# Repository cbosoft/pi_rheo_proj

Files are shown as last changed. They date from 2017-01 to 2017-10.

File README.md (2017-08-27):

# RPi-R #

Raspberry Pi Rheometer. A rheometer using a Taylor-Couette cell along with 
a plethora of sensors to record a bunch of data like temperature, revolution
speed, motor supply current etc etc.

The project has been extended, so more effort can be put into designing the 
hardware.

With now a choice of motor and what-have-you, a better (read: working) rheometer
can be produced in the next few months. A few different design are being considered,
one possible novel method which could be cool (although there is nothing new under
the sun, someone must have tried it before).

I have started with a software overhaul, and will continue to ponder what direction
to go in with the hardware until October, when I will begin to put plans into action.

## Changelog ##

**v0.1.5**

- Cleaned up gui
- Rewrote recalibration algo
- Added cal override (if cal is wrong or previous was better whatever)
- General tidying of script
- Removed quick run as an option (when would this ever be used?)
- Added info about why each package is being imported
- Removed "Plot" as a main menu option - this may return later on
- Removed complex menu system
- Removed rheometry calculation function (was incorrect anyway)

## Rough Index ##

```
/bin                            code lives here
/etc/data.xml                   meta data lives here (calibrations, rheometer geometry)
/logs                           data logged from experimental runs lives here (temporary)
/misc/datasheets                hardware datasheets live here
/plot                           scripts for plotting results live here
```

## License Spiel ##

*Distributed under GNU General Public License (GPL).*

*You can use this as much as you like, share it as you like, whatever.*

*However, there is no warranty or guarantee that it will actually work.*

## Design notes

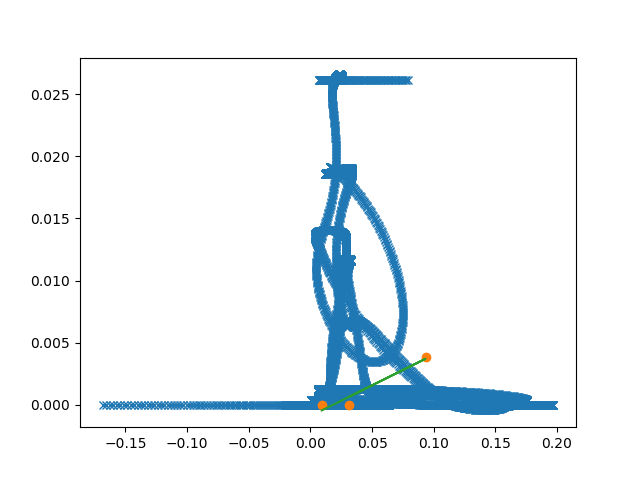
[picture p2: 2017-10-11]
etc/trd.png

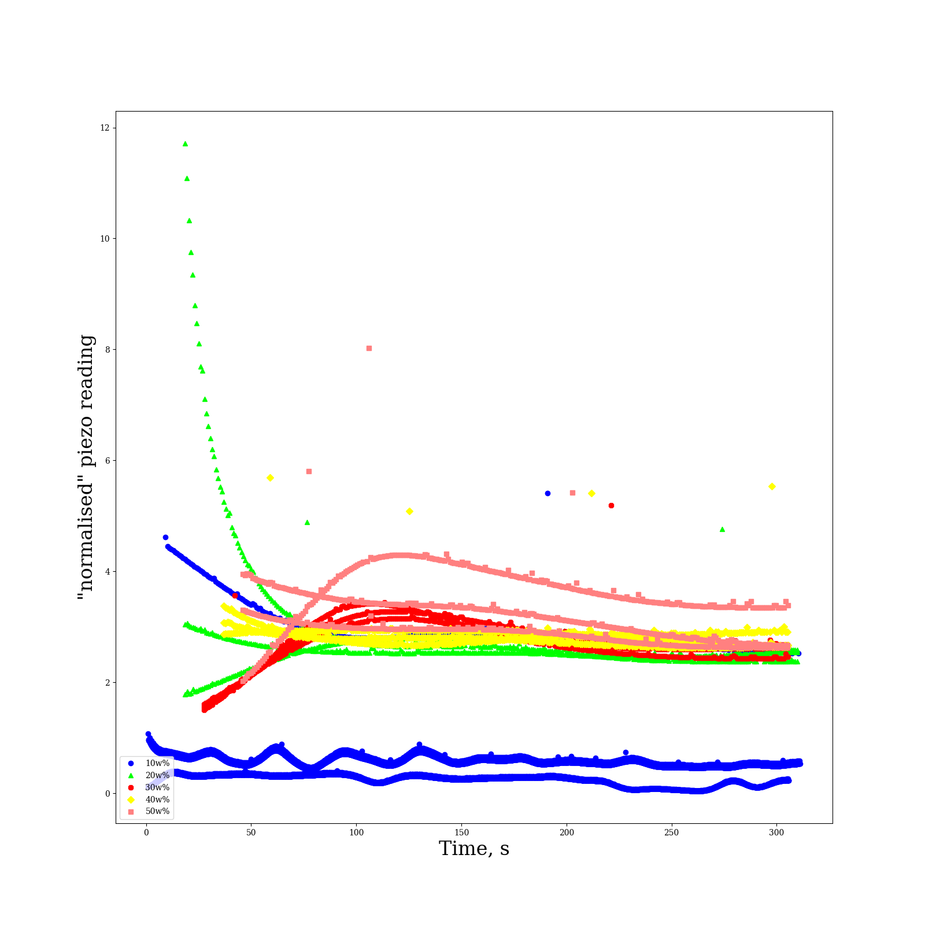
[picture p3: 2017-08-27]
plots/logs_piezo_compare_normalised.png

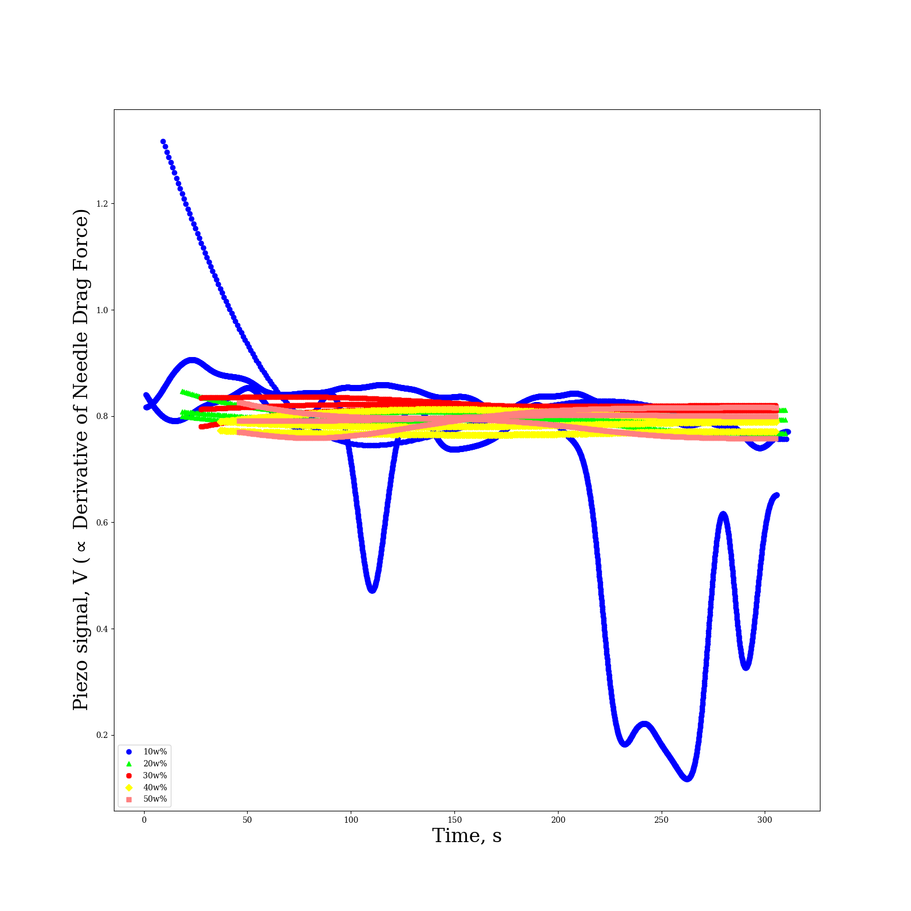
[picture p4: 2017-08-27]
plots/logs_piezo_compare.png

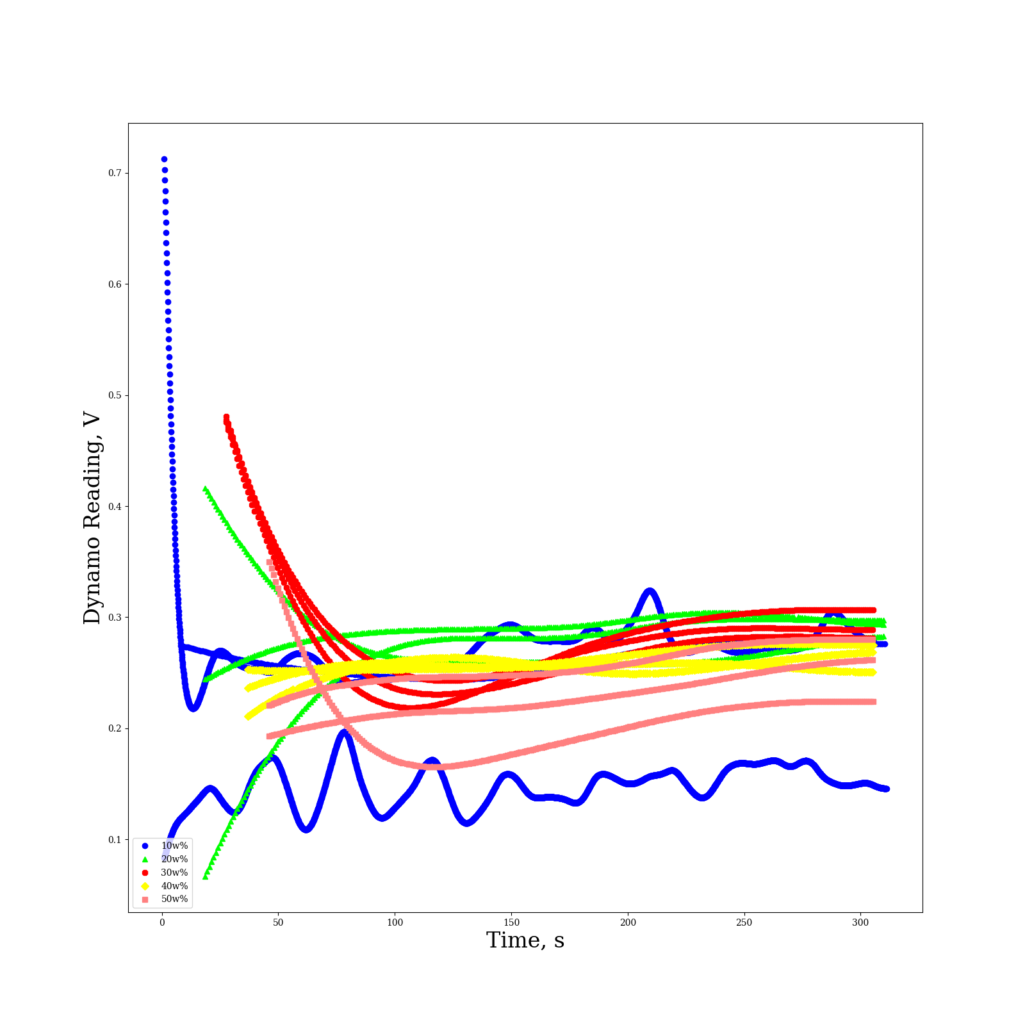
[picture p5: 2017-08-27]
plots/logs_piezo_compare_speeds.png

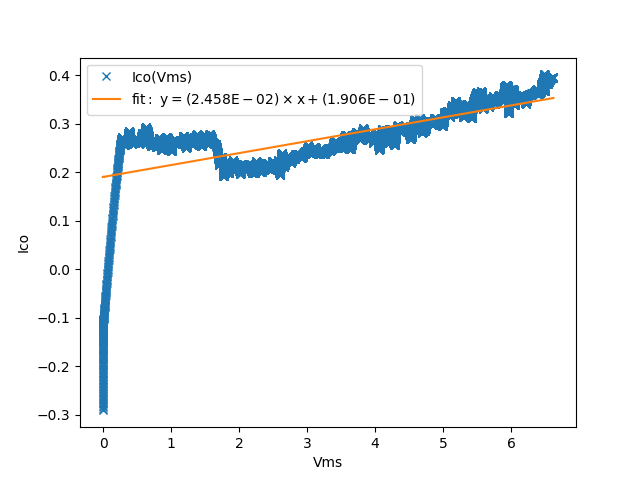
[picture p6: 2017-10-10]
plots/cal_cur.png

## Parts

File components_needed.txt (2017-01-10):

Component,Size,Link
Motor Speed Controller,,
Digital Potentiometer,10k,http://uk.rs-online.com/web/p/digital-potentiometers/6878458/
Digital Pot Surface Mount to Through Hole,MSOP,http://uk.rs-online.com/web/p/surface-mount-smt-to-through-hole-adapter-boards/6564897/
Capacitor 1,10uF,http://uk.rs-online.com/web/p/aluminium-capacitors/0117035/
Capacitor 2,470uF,http://uk.rs-online.com/web/p/aluminium-capacitors/5261884/
Transistor,max 65w and 6A,http://uk.rs-online.com/web/p/bipolar-transistors/7905292/

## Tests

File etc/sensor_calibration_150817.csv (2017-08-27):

t | dr | cr | cr2a | cr2b | pv | fdr | fcr | T | Vpz1 | Vpz2 | Vpzbg | Vadcbg
1502799552.038952 | 0.200 | 0.754 | 1.470 | 1.473 | 0 | 0.200 | 0.754 | 0.000 | 0.0580078125 | 0.01611328125 | 0.01611328125 | 0.02578125
1502799552.141647 | 0.738 | 0.754 | 1.476 | 1.470 | 0 | 0.738 | 0.754 | 0.000 | 0.0580078125 | 0.0 | 0.0 | 0.0
1502799552.243836 | 0.645 | 0.754 | 1.473 | 1.473 | 0 | 0.645 | 0.754 | 0.000 | 0.0580078125 | 0.0 | 0.0 | 0.0
1502799552.347707 | 0.677 | 0.754 | 1.502 | 1.492 | 0 | 0.677 | 0.754 | 0.000 | 0.0580078125 | 0.0064453125 | 0.0064453125 | 0.0064453125
1502799552.450571 | 0.625 | 0.780 | 1.511 | 1.502 | 0 | 0.625 | 0.780 | 0.000 | 0.064453125 | 0.0064453125 | 0.0064453125 | 0.0064453125
1502799552.552842 | 0.110 | 0.777 | 1.508 | 1.492 | 0 | 0.110 | 0.777 | 0.000 | 0.05478515625 | 0.00322265625 | 0.00322265625 | 0.0
1502799552.654741 | 0.148 | 0.780 | 1.508 | 1.502 | 0 | 0.148 | 0.780 | 0.000 | 0.05478515625 | 0.00322265625 | 0.00322265625 | 0.00322265625
1502799552.756504 | 0.145 | 0.780 | 1.518 | 1.492 | 0 | 0.145 | 0.780 | 0.000 | 0.05478515625 | 0.0 | 0.0 | 0.0
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

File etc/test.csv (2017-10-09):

t | f_spd0 | r_spd0 | f_spd1 | r_spd1 | f_spd2 | r_spd2 | cra | crb | pv | T | Vpz | Vms
1507542908.593720 | 0.000 | 0.000 | 0.000 | 0.000 | 0.000 | 0.000 | 2.519 | 0.039 | 25.000 | 0.000 | 0.0870967741935 | 0.000
1507542908.605269 | 0.000 | 0.000 | 0.000 | 0.000 | 0.000 | 0.000 | 2.490 | 0.003 | 25.000 | 0.000 | 0.0451612903226 | 0.000
1507542908.616724 | 0.000 | 0.000 | 0.000 | 0.000 | 0.000 | 0.000 | 2.500 | 0.000 | 25.000 | 0.000 | 0.0 | 0.000
1507542908.628102 | 0.000 | 0.000 | 0.000 | 0.000 | 0.000 | 0.000 | 2.494 | 0.035 | 25.000 | 0.000 | 0.103225806452 | 0.013
1507542908.639447 | 0.000 | 0.000 | 0.000 | 0.000 | 0.000 | 0.000 | 2.526 | 0.000 | 25.000 | 0.000 | 0.0 | 0.052
1507542908.650724 | 0.000 | 0.000 | 0.000 | 0.000 | 0.000 | 0.000 | 2.513 | 0.055 | 25.000 | 0.000 | 0.135483870968 | 0.052
1507542908.662021 | 0.000 | 0.000 | 0.000 | 0.000 | 0.000 | 0.000 | 2.555 | 0.000 | 25.000 | 0.000 | 0.0 | 0.065
1507542908.673295 | 0.000 | 0.000 | 0.000 | 0.000 | 0.000 | 0.000 | 2.516 | 0.035 | 25.000 | 0.000 | 0.0838709677419 | 0.077
1507542908.684552 | 0.000 | 0.000 | 0.000 | 0.000 | 0.000 | 0.000 | 2.542 | 0.000 | 25.000 | 0.000 | 0.0322580645161 | 0.116
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

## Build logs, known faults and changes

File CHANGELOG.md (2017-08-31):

## v0.1.8 ##
- Control script overhaul

## v0.1.7 ##
- Tidied display function
- Removed 30AHES recording
- Added dynamo filter recording and speed calculation

## v0.1.6 ##
- Added proper changelog tracking
- Added rheology data calculation to logger
- Added motor calibration
- Tidied plothelp.py
- Added general plot function to plothelp.py
- Started docstring overhaul

## v0.1.5 ##

- Cleaned up gui
- Rewrote recalibration algo
- Added cal override (if cal is wrong or previous was better or whatever)
- General tidying of script
- Removed quick run as an option (when would this ever be used?)
- Added info about why each package is being imported
- Removed "Plot" as a main menu option - this may return later on
- Removed complex menu system
- Removed rheometry calculation function (was incorrect anyway)

## v0.1.3 and previous ##

- All knowledge of this period has been lost in the annals of history
- It can be inferred that at some point The Software was written, and at some point The Hardware was assembled.

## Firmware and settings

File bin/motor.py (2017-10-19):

'''
    Facilitates the control of a motor using dig_pot.py and adc.py.
    
    Controls the supply voltage sent to the motor in to control the speed.
    Data is logged using methods from adc.py. Noise is removed from the data
    using methods from filter.py. Temperature sensing data is obtained using
    tempsens.py.
    
    Author: Chris Boyle (christopher.boyle.101@strath.ac.uk)
'''

# System
import sys
import time
import os
import thread as td
from warnings import warn

# 3rd Party
try:
    import RPi.GPIO as gpio
except ImportError:
    import dummygpio as gpio
import numpy as np
#from PID import PID as pid

# RPi-R
#from filter import filter as ft
#from dig_pot import MCP4131 as dp
from adc import MCP3008 as ac
from control import pid_controller as pid
from tempsens import ds18b20 as ts
import dproc

class motor(object):
    '''
    Usage:
    
    object = motor.motor(**kwargs)
    
    Creates a new instance of a motor interface object.
    
    **kwargs:
        startnow        (bool)          Start polling as soon as the instance is created
        adc_vref        (float)         Voltage reference value. Default is 3.3
        poll_logging    (bool)          Indicates whether to log to file or not. Default is True.
        therm_sn        (string)        Serial number of the thermocouple. Used in 1-wire communication.
                                        Default is '28-0316875e09ff'
        i_poll_rate     (float)         Inverse poll rate: time to wait in between logging data. Default is 0.1
        pic_tuning      (float, float)  Tuning of PI controller. Kp and Ki respectively. Default is (0.2, 0.15)
        relay_pin       (integer)       Pin number which can be used to control the relay.
    '''
    # Logging
    poll_running = False  # is the speed currently being polled?
    poll_logging = True  # Will log every (i_poll_rate)s if this is True
    this_log_name = ""
    debug = False

    def __init__(self, startnow=False, adc_vref=3.3, poll_logging=True, therm_sn="28-0316875e09ff",
                 log_interval=0.01, tuning=(1.8, 2.845, 0.0), opt_pins=[21]):
        '''
        object = motor.motor(**kwargs)
        
        Creates a new instance of a motor interface object.
        
        **kwargs:
            startnow        (bool)          Start polling as soon as the instance is created. Default is False
            adc_vref        (float)         Voltage reference value. Default is 3.3
            poll_logging    (bool)          Indicates whether to log to file or not. Default is True.
            therm_sn        (string)        Serial number of the thermocouple. Used in 1-wire communication.
                                            Default is '28-0316875e09ff'
            i_poll_rate     (float)         Inverse poll rate: time to wait in between logging data. Default is 0.1
            pic_tuning      (float, float)  Tuning of PI controller. Kp and Ki respectively. Default is (0.2, 0.15)
            relay_pin       (integer)       Pin number which can be used to control the relay. Default is 18
        '''
        # Debug status string
        self.dss = ""

        # GPIO setup
        self.gpio_ready = False
        self.opt_pins = opt_pins
        self.setup_gpio()
        
        # controller
        self.pidc = pid(tuning)
        self.speed = 0.0
        self.control_stopped = True

        # Set sensor variables
        self.aconv = ac(cs_pin=1, vref=adc_vref)
        self.therm = ts(therm_sn)
        self.log_interval = log_interval
        self.volts = [0.0] * 8
        self.thermo_running = True
        self.temperature_c = 0.0
        self.temp_c_interval = 0.5
        
        # Set up logs
        self.poll_logging = poll_logging
        
        # Start threads
        if (startnow): self.start_poll(log_name)
        td.start_new_thread(self.thermometer, tuple())
    
    def setup_gpio(self):
        if self.gpio_ready: return
        # GPIO setup
        gpio.setmode(gpio.BCM)
        
        # Setup PWM pin
        self.pwm_pin = 18
        gpio.setup(self.pwm_pin, gpio.OUT)
        self.pwm_er = gpio.PWM(self.pwm_pin, 500)  # 0.5kHz
        self.ldc = 0.0
        self.pwm_er.start(0.0)
        
        # Setup optical encoder pins
        self.thens    = [time.time()] * (len(self.opt_pins) * 2)
        self.rps      = [4.0] * len(self.opt_pins)
        self.rps.extend(self.rps)
        self.speeds   = [0.0] * (len(self.opt_pins) * 2)
        self.misses   = [0] * (len(self.opt_pins) * 2)
        self.t_misses = 10 # how many "incorrect" values to ignore before accepting
        self.opt_dict = dict()

        for p in self.opt_pins:
            self.opt_dict[p] = len(self.opt_dict)
            gpio.setup(p, gpio.IN, pull_up_down=gpio.PUD_UP)
            gpio.add_event_detect(p, gpio.BOTH, callback=self.opt_fr)
        gpio.setwarnings(False)
        self.gpio_ready = True

    def opt_fr(self, channel):
        ch_idx = self.opt_dict[channel]
        if gpio.input(channel): ch_idx += len(self.opt_pins)
        now = time.time()
        dt = now - self.thens[ch_idx]
        prov_spd = (60.0) / (dt * self.rps[ch_idx]) # speed in rpm
        if ((prov_spd < (2 * self.speeds[ch_idx])) or (self.misses[ch_idx] > self.t_misses)):
            self.speeds[ch_idx] = prov_spd
            self.misses[ch_idx] = 0
        else:
            self.misses[ch_idx] += 1
        self.thens[ch_idx] = now
        #print "ch: ", channel, "idx:", ch_idx
    
    def get_speed(self):
        return np.average(self.speeds)
        
    def thermometer(self):
        while (self.thermo_running):
            if self.therm.check_sn(): 
                self.temperature_c = self.therm.read_temp()
            else:
                self.thermo_running = False
            time.sleep(self.temp_c_interval)
        
    def new_logs(self, log_name="./../logs/log.csv"):
        '''
        motor.new_logs(**kwargs)
        
        Creates a new set of logs. Useful for running tests one after another.
        
        **kwargs:
            log_name        (string)            Indicates name of new log file.
        '''
        # Try closing old log file
        try:
            self.logf.close()
        except:
            pass

        # Create log
        if (self.poll_logging):
            self.this_log_name = str(log_name)
            self.logf = open(self.this_log_name, "w")
            self.logf.write("t,spd0,spd1,spd2,spd3,spd4,spd5,Vcr,adc0,dc,T,Vpz,Vms\n")

    def start_poll(self, name="./../logs/log.csv", controlled=False, debug_=False):
        '''
        motor.start_poll(**kwargs)
        
        Starts the data logging process. Launches a new thread which will continuously monitor the sensors and record
        the desired data. Saves file to <motor.log_dir>/<name>
        
        **kwargs:
            name            (string)            Indicates name of new log file. 'DATETIME' will be replaced by date
                                                and time of run. Default is 'DATETIME'
            controlled      (bool)              Indicates whether the control thread should be started or not.
        '''
        self.debug = debug_
        self.setup_gpio()
        if controlled: self.start_control()

        if self.poll_logging:
            self.new_logs(log_name=name)
        if (not self.poll_running):  # if not already running
            td.start_new_thread(self.poll, tuple())
    
    def start_control(self):
        '''
        motor.start_control()
        
        Starts the PI control of the speed. Launches a new thread which will use the control library to decide how to 
        alter the motor's supply voltage in order to maintain the setpoint.
        '''
        if self.control_stopped:
            self.control_stopped = False
            td.start_new_thread(self.control, tuple())
            
    def update_setpoint(self, value):
        '''
        motor.update_setpoint(value)
        
        Sets the new setpoint on the controller.
        
        Parameters:
            value       (float)         The strain value for the control system to target, (s^-1).
        '''
        self.pidc.set_point = value
    
    def control(self):
        '''
        motor.control()
        
        When motor.start_control() is called, a thread is created running this method. Continuously gets the speed 
        (filtered) from the sensor detection thread and calculates the control action (new motor supply voltage) to
        best maintain the setpoint.
        
        This will repeat until motor.control_stopped becomes True.
        '''
        while not self.control_stopped:
            self.speed = self.get_speed()
            av_speed = (2 * np.pi * self.speed) / 60.0
            self.speed_rads = av_speed
            control_action = self.pidc.get_control_action(dproc.get_strain(av_speed))
            #control_action = self.pidc.get_control_action(av_speed)
            if control_action > 100.0: control_action = 100.0
            if control_action < 0.0: control_action = 0
            self.set_dc(control_action)
            time.sleep(0.01)

    def read_sensors(self):
        '''
        motor.read_sensors()
        
        Reads from every channel of the ADC (CH0 to CH7).
        
        Returns:
            out     ([float] * 8)       List of values read from ADC.
        '''
        out = list()
        for a in range(0, 8):
            out.append(self.aconv.read_volts(a))
        return out
        
    def poll(self):
        '''
        motor.poll()
        
        When motor.start_poll() is called, a thread is created running this method. Continuously reads the sensors and 
        writes the values out to the log file.
        
        This will repeat until motor.stop_poll() is called, or motor.poll_running becomes False.
        '''
        self.poll_running = True
	
        while (self.poll_running):
            # At the third tone, the time will be...
            t = time.time()
            
            # Read sensors
            self.volts = self.read_sensors()
            stw = list(self.speeds)
            
            if len(stw) < 6: stw.extend([3.14] * (6 - len(stw)))
            
            if (self.poll_logging and not self.debug):
                #                   t       spd0   spd1    spd2    spd3    spd4    spd5    cra    adc0     dc      T     Vpz  Vms
                self.logf.write(("{:.6f}, {:.3f}, {:.3f}, {:.3f}, {:.3f}, {:.3f}, {:.3f}, {:.3f}, {:.3f}, {:.3f}, {:.3f}, {}, {:.3f} \n").format(
                    t, stw[0], stw[1], stw[2], stw[3], stw[4], stw[5], self.volts[2], self.volts[1], self.ldc, self.temperature_c, self.volts[4], (self.volts[7] * dproc.vmsmult)))
            elif (self.debug):
                self.logf.write(("{:.6f}, 80, 80, 80, 80, 80, 80, 3, 0, 50, 15, 2, 3 \n").format(t))
                    
            # delay for x seconds
            time.sleep(self.log_interval)
        self.clean_exit()

    def set_dc(self, value):
        '''
        motor.set_dc(value)
        
        Sets the duty cycle of the PWM - affecting the voltage supply to the motor.
        
        Parameters:
            value       (float)     Ratio of the 'high' part of the PWM signal to the
                                    'low' part. 100 is always on, 0 is never on.
        '''
        if value < 0.0:
            value = 0.0
        elif value > 100.0:
            value = 100.0
        
        self.ldc = value
        self.pwm_er.ChangeDutyCycle(value)
                   
    def clean_exit(self):
        '''
        motor.clean_exit()
        
        Cleanly shuts down sensor poll and control threads, as well as tidying up the GPIO settings and closing log 
        files.
        
        Should always be called when finished using the motor.
        '''
        # Halt threads
        self.poll_running = False
        self.control_stopped = True
        self.spf_needed = False
        self.thermo_running = False
        
        # Stop motor
        time.sleep(1)
        self.set_dc(0.0)
        time.sleep(2)
        self.set_dc(0.0)
        time.sleep(2)        
        
        # Release GPIO and whatnot
        self.pwm_er.stop()
        gpio.cleanup()
        self.gpio_ready = False
        
        # Close log files
        #self.opt_log.close()
        if (self.poll_logging):
            self.logf.close()

if __name__ == "__main__":
    print __doc__
    print motor.__doc__

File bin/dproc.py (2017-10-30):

'''
dproc.py

Provides data about the rheometer (geometry etc) as well as methods useful in data processing 
and plotting

Provides run-time access to the information stored in the /etc/data.xml file, including access 
to calibrations and the geometry of the cylinders.

Also has a few functions that allow the easy use of the calibrations ("get_supply_voltage(pv)" 
for example)
'''

# System
import math
from copy import copy

# 3rd Party
import xml.etree.ElementTree as ET
import numpy as np
from numpy import *
from scipy.optimize import curve_fit
try:
    import spidev # will error if not on rpi
    from matplotlib import use as mpluse
    mpluse('Agg')  # for plotting from commandline (with no xserver or anything)
except:
    pass # not on rpi, don't need to use (!xserver) as gui backend
import matplotlib.pyplot as plt
import pandas as pd

# RPi-R
from filter import filter

######################################################################################################################## XML FUNCTIONS
def writeout(path="./../etc/data.xml"):
    '''
    writeout(**kwargs)
    
    Writes the contents of a data file.
    
    **kwargs:
        path        (string)        Path to data.xml. Default is './../etc/data.xml'
    '''
    nuroot = ET.Element("all-data")
    # update xml tree
    
    # for every k/v pair in data, add node to xml
    for k, v in data.iteritems():
        nuroot.insert(1, ET.Element(k, {"value":str(v)}))

    #nuroot.write(path)
    tree = ET.ElementTree(nuroot)
    tree.write(path)

def readin():
    global root
    root = ET.parse('./../etc/data.xml').getroot()
    #root = ET.parse('./test.xml').getroot()

    data = dict()
    
    for child in root:
        data[child.tag] = float(child.attrib["value"])

    return data

root = ""
data = readin()

######################################################################################################################## GLOBALS/runtime
vmsmult = 4.0 # due to voltage divider taking motor supply voltage down to a level the ADC can read

# Noload/maxeff/stall values taken from datasheet: https://www.neuhold-elektronik.at/datenblatt/N7029.pdf
## NO LOAD
Vms_noload_V = 3.0
omega_noload_rpm = 3500
omega_noload_rads = omega_noload_rpm * (2.0 * np.pi / 60.0)

## STALL
Vms_stall_V = 3.0
Ims_stall_A = 0.39
T_stall_Nm = 0.00251

## MAX EFFICIENCY
T_maxeff_Nm = 0.00048
Vms_maxeff_V = 3.0
omega_maxeff_rpm = 2830.0
omega_maxeff_rads = omega_maxeff_rpm * (2.0 * np.pi / 60.0)
Ims_maxeff_A = 0.093

# Resistance measurements - lots because paranoid
R = np.average([15.9, 13.6, 16.4, 13.0, 13.3, 13.6, 13.6, 14.7, 15.4, 13.7, 16.4, 13.5, 17.4, 17.0])

## Calculate kv
kv_noload = Vms_noload_V / omega_noload_rads
kv_stall = (T_stall_Nm * R) / Vms_stall_V
kv = np.average([kv_noload, kv_stall])

## Get mass of inner cylinder
rho_nylon = 1150.0 # kg/m3
m_cyl_b = rho_nylon * (data['icor'] ** 2) * data['ich']
m_cyl_t = rho_nylon * 2 * (0.01 ** 3)
m_cyl = m_cyl_b + m_cyl_t


######################################################################################################################## VISCOSITY CALCULATION STUFF
def get_mu_of_T(material_n, T_c, misc_data=None):
    '''
    get_mu_of_T(material_n, T_c, misc_data=None
    
    Uses functions from various data sources in order to calculate continuously
    the viscosity data of various compounds and mixtures from the current temperature.
    
    Parameters
    ----------
    
    material_n      (string)            The name of the material to calculate the viscosity for.
                                        Can also be a definition of a mixture e.g. 'glycerol+water'
                                        the '+' character is necessary, and all mixture definitions
                                        must follow the same formula.
    
    T_c             (float/iterable)    The temperature(s) in celsius used to calculate the
                                        viscosity of the material.
    
    misc_data       (float/string)      For mixtures, there is often required to be extra information
                                        to calculate the viscosity - such as the composition.
                                        This can be set here depending on the function requirements.
    
    Returns
    -------
    
    mu_out          (float)             The viscosity of the specified material/mixture
    
    References
    ----------
    
    [Cheng 2008]    "Formula for the Viscosity of a Glycerol-Water Mixture",
                    Nian-Sheng Cheng, Ind. Eng. Chem. Res. 2008, 47, 3285-3288
    '''
    
    materials_dict = {
    
        "glycerol":0,
        
        "water":1,
        
        "glycerol+water":2
        
        }
    
    function_index = 0
    
    try:
        function_index = materials_dict[material_n]
    except:
        raise Exception("Material not known! Did you spell it correctly?")
    
    # Alternative T units
    T_K = T_c + 273.15                  # Tabs, Kelvin
    T_F = T_c * (9.0/5.0) + 32.0        # Trel, Fahrenheit
    T_R = T_F + 459.67                  # Tabs, Rankine
    
    mu_out = 0.0
    
    if function_index == 0:
        # Material is glycerol
        #
        # Function is taken from [Cheng 2008]
        mu_out = ((12100.0 * (e ** (((-1232.0 + T_c) * T_c) / (9900.0 + (70.0 * T_c))))) * 0.001)
    elif function_index == 1:
        # Material is water
        #
        # Function is taken from [Cheng 2008]
        mu_out = ((1.79 * (e ** (((-1230.0 - T_c) * T_c) / (36100.0 + (360.0 * T_c))))) * 0.001)
    elif function_index == 2:
        # Material is aqueous glycerol solution
        #
        # Method is taken from [Cheng 2008]
        a = (0.705 - 0.0017 * T_c)
        b = ((4.9 + 0.036 * T_c) * (a ** 0.25))
        mug = ((12100.0 * (e ** (((-1232.0 + T_c) * T_c) / (9900.0 + (70.0 * T_c))))) * 0.001)
        muw = ((1.79 * (e ** (((-1230.0 - T_c) * T_c) / (36100.0 + (360.0 * T_c))))) * 0.001)
        cm = float(misc_data)
        alpha = (1.0 - cm + ((a * b * cm * (1.0 - cm)) / ((a * cm) + (b * (1.0 - cm)))))
        mu_out = (muw ** alpha) * (mug ** (1.0 - alpha))
    return mu_out

def get_current(cv):
    cu = ((cv - 2.5) / 0.185) # current = (signal - (2.5v offset)) * (0.185 v/A sensitivity)
    return cu

def get_strain(omega_rads):
    '''
    get_strain(omega_rads)

    Using the couette cell geometry, converts the angular speed of the inner cylinder to
    the strain experienced by the fluid.
    '''
    strain_invs = omega_rads * (data["icor"] / (data["ocir"] - data["icor"])) 
    return strain_invs
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

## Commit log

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2017-01-05 multi threading support for image recognition script
    need to invest in a fan for the pi, it keeps overheating
2017-01-10 Update and rename components_needed.txt to components_needed.csv
    [components_needed.csv]
2017-01-10 added circuit diagrams
    [components_needed.csv]
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2017-01-14 added circuit schematics for speed control and detection
    [circdigpotclose.fzz, circspeedcontr.fzz, circspeedcontrclose.fzz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]
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2017-01-17 added risk assessment, updated workaround for hall effect chin (do not use)
    [circspeeddetworkaround.fzz]
2017-01-17 added circuit diagram for testing whether the hall effect sesnor works (simple LED ON when magnet is near)
    [circhallcheck.fzz]
2017-01-17 updated speed detection circuit (it works now!)
    [circspeeddet.fzz]
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2017-01-21 updated risk assessment, diagrams, report
    [circspeedcontr.fzz]
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2017-01-26 new circuit design, new datasheet for opamp on the new circuit
    [circspeedcontr2.fzz]
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2017-02-01 added voltage/potvalue graph
    [voltperval..xlsx]
2017-02-01 updates and such
    [voltperval..xlsx]
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2017-02-02 updated log
    [voltperval..xlsx]
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2017-03-15 SPRING CLEAN 2
    [cell_geom.csv, hall_histo_bad.csv, intermittent_load_short.csv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]
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2017-03-17 updates and friday things idek
    [cell_geom.csv, motor_charact_main.csv]
2017-03-21 The Big Tidy
    [circdigpotclose.fzz, circhallcheck.fzz, circspeedcontr.fzz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]
2017-03-22 updated report
    [voltvval.csv]
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2017-03-26 updated report (noise filtering, rheometry sections)
2017-03-29 updated logs and scripts
    [stall_torque_v_current_old.csv]
2017-03-30 updated control, test
    [template_run_data.csv]
2017-03-30 test results
    [log_13 28 31.csv, log_13 30 21.csv]
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2017-03-31 control system fixed (?)
    [0.015_0.01.csv, 0.01_0.01.csv, 0.01_0.011.csv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]
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2017-04-03 mad tidyings yo
    [control_test_log.csv]
2017-04-05 updated geometry (includes volume)
    [cell_geom.csv]
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2017-04-10 changed calibration method - fixed calc i think
2017-04-10 added lab data, also minor fixes
    [log_13 01 17.csv, log_13 02 56.csv, log_13 03 42.csv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]
2017-04-11 added lit for glycerol solution viscosity
    [viscs.ods]
2017-04-13 added lab results
    [g100.csv, g8887.csv, g9375.csv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]
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2017-04-19 new data, different calibration methods
    [dual_hes_long100.csv]
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2017-04-22 updated report, figures
    [intermittent_load_short.csv, std_sweep.csv]
2017-04-24 new figures
    [contr_test.csv]
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2017-05-12 Finished stall torque calibration run through
    [rheometer.py]
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2017-05-16 Bug fixes and corrections (Don't write code at 5am)
    [motor.py, rheometer.py]
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2017-05-19 Removed csvs from repo
    [cell_geom.csv, contr_test.csv, dual_hes_long100.csv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]
2017-05-19 Tidying up
    [viscs.ods, voltperval..xlsx]
2017-05-20 Added logs
    [sensor_calibration_100417.csv]
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2017-05-20 Added missing "OUT" var
    [dummygpio.py]
2017-05-20 Added missing "volts" list
    [motor.py]
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2017-05-25 Updated GUI, nicer package importer
    Also minor bugfixes: commas missing, extra brackets, too few brackets etc etc
    [rheometer.py]
2017-06-05 Bugfixes, typos, silly mistake fixings...
    [motor.py, rheometer.py]
2017-06-06 added cal logs
    [log_00 01 25.csv, log_00 02 52.csv, log_23 59 09.csv]
2017-06-06 Bug fixes
    Automatic calibration is sort of working now!
    [motor.py, rheometer.py, tempsens.py]
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2017-06-14 Added logs from tests today
    [rheometry_test_1248_120617.csv, rheometry_test_1255_120617.csv, rheometry_test_1303_120617.csv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]
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2017-06-21 Updated with background noise recording + filtering
    [motor.py]
2017-06-21 Tidying old logs away
    [rheometry_test_1248_120617.csv, rheometry_test_1255_120617.csv, rheometry_test_1303_120617.csv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]
2017-06-22 New logs
    [rheometry_test_120617_1338.csv, rheometry_test_120617_1351.csv, rheometry_test_120617_1358.csv]
2017-06-26 Added new logs (long run, saw-tooth voltage supply wave)
    [rheometry_test_120617_1416.csv, rheometry_test_230617_1507.csv, rheometry_test_230617_1518.csv]
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2017-06-26 Updated and fixed menu system
    -improved run information
    -implemented real strain tracking
    [rheometer.py]
2017-06-28 Minor updates a pi related fixins
    [rheometer.py]
2017-06-28 NeW LoGs!1!
    [rheometry_test_280617_1204.csv, rheometry_test_280617_1417.csv, rheometry_test_280617_1431.csv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]
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2017-08-15 Commented out transfer function creator -- Does not work for early scipy available on RPi2?! -- Pip cannot install v0.19.1 - try fix soon
    [control.py]
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2017-08-16 Overhaul (0.1.5 changelog): -- Cleaned up gui -- Rewrote recalibration algo -- Added cal override (if cal is wrong or previous was better whatever) -- General tidying of script -- Removed quick run a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
    TODO:
    -- Make program/functions versatile to hardware changes
    -- Make more use of the resx.py package
    [rheometer.py]
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2017-08-27 Added rheology calc script
    Also tidied up a bit
    [sensor_calibration_150817.csv]
2017-08-28 Fixed overactive docstring viewer
    [filter.py]
2017-08-28 Removed broken ref to old results calc function
    [rheometer.py]
2017-08-28 Water test results Monday 28 August
    [rheometry_test_0wtpd0_280817_0945.csv, rheometry_test_0wtpd0_280817_1008.csv]
2017-08-29 Added logs from testing of new filter
    [log_10 43 46.csv, log_10 44 46.csv, log_10 45 29.csv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]
2017-08-29 Added log after new filter applited (cutoff 0.15Hz)
    [rheometry_test_filter_test_8_290817_1105.csv]
2017-08-29 Swapped out for PID.py (ivMech's code)
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2017-08-29 Typo fixed in recal
    [rheometer.py]
2017-08-29 THE GREAT CONTROL TESTING OF SUMMER '17
    [test.csv]
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2017-08-31 new cals with new hw
    [rheometry_test_control_test_1_290817_1118.csv, sensor_calibration_290817_1150.csv, sensor_calibration_290817_1201.csv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]
2017-09-01 Testing PWM voltage control: I think the ADC may be broken...
    [test.csv, test_weird_pwm_results.csv]
2017-09-06 Testing new PWM voltage supply
    [test.csv]
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2017-09-08 new speed det test
    [opt_log.csv, test.csv]
2017-09-11 New encoder disk trial 1
    [opt_log.csv, test.csv]
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2017-09-14 fixed Inactive warning bug
    [tempsens.py]
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2017-09-14 idk whats changed but w/e
    [opt_log.csv]
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2017-09-15 tried to fix adc :/
    [adc.py, motor.py, tadc.py]
2017-09-15 opsens 0+1 working, opsens 2... not so much
    [test.csv]
2017-09-18 FIXED THE MOST FRUSTRATING ERROR EVER
    I had mistakenly thought I'd cracked the datasheets cryptic messages
    but I ended up writing gibberish - UNKNOWINGLY - for 6 months.
    All ADC voltages ever read are complete garbage.
    They are now fixed.
    Yay.
    [adc.py]
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2017-09-18 FIXED THAT GODDAMN ADC
    [tadc.py]
2017-09-18 test logs for testing
    [test.csv, test_calcd.csv]
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2017-09-19 Bugfixes
    New calibration fucntion employed (hopefully works now)
    Various typos fixed
    Removed 2nd ACS712 - buggy
    [rheometer.py]
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2017-09-19 log files from calibrationinging
    [ccal_19.09.17-1415.csv, mcal_glycerol_1.411_pas_19.09.17-1436.csv, mcal_water_0.01_pas_19.09.17-1442.csv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]
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2017-09-26 Fixed torque calc error
    -silly mistake (I misread one of my equations, tau as T and T as tau :S )
    -also fixed speed calc error (sending to functions as RPMs instead of rads)
    [calculate_viscosities.py, motor.py, rheometer.py]
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2017-09-26 Added beginnings of autotune script
    Maybe sort of wokring oscillating test function
    [auto_tune.py, lmftest.py]
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2017-09-27 water rheology test Wednesday 27 9 17
    [rheometry_test_water_270917_1513.csv]
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2017-09-27 maybe fixed the iemf calibration issue...
2017-09-27 changed visc in calc to more accurate number
    [mcal_glycerol_2.65_pas_19.09.17-1436_calcd.csv]
2017-09-28 chasing bugs
    [ccal_19.09.17-1415.csv, test.csv]
2017-10-09 New motor + preliminary calibrations
    [ccal_09.10.17-0940.csv, ccal_09.10.17-0944.csv, test.csv]
2017-10-09 new motor better cal
    [mcal_mostlyglycerol_2.0_pas_09.10.17-1252_calcd.csv, mcal_water_0.01_pas_09.10.17-1243_calcd.csv, rheometry_test_mostlyglycerol_091017_1301.csv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]
2017-10-09 new motor fixins
2017-10-10 test archives for testing
    [tmcal_pure-glycerol_glycerol+water@1.0_date_calcd.csv, tmcal_pure-water_glycerol+water@0.0_date_calcd.csv]
2017-10-11 Corrected 'tau' -> T in calibration storage and calculations
2017-10-11 Reverted poll interval to 10ms (from 1ms)
    [motor.py]
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2017-10-12 doesn't really do what it says on the tin anymore...
    [calculate_viscosities.py]
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2017-10-30 Added voltage sweep with new set up
    [empty_vsweep.csv, water_vsweep.csv]
2017-11-08 Added glycerol of known viscosity tests (its no longer a guess!)
    [rheometry_test_glyc_0_081117_1416.csv]
2017-11-28 Added glycerol aqueous solution logs
    [rheometry_test_solA1_281117_1354.csv, rheometry_test_solA2_281117_1358.csv, rheometry_test_solA3_281117_1406.csv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]
